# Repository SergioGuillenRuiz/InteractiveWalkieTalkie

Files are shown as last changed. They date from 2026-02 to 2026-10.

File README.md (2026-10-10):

# Proyecto Gogoaty — walkie-talkie LoRa con pantalla

Un par de equipos de bolsillo (ESP8266 + módulo LoRa SX1276 + pantalla OLED, **dos botones y un potenciómetro**)
que se mandan mensajes cifrados por radio, sin móvil ni internet: texto en Morse, mensajes rápidos con icono,
letras con una rueda, frases por piezas y dibujos de 24×24 píxeles. Un hipopótamo anima la pantalla, avisa
cuando llega algo y se duerme solo. Incluye varios juegos (Tetris cooperativo, Poker, Tres en raya…) y un radar
para localizar al otro equipo. Versión del firmware: **V2.0**.

> **Estado.** Todo lo descrito aquí está verificado en el **simulador** (`sim/`, más de 40 tests con la radio y el
> chip modelados). **Falta probarlo en la placa**: ver [`path.md`](path.md) (hoja de ruta, riesgos y decisiones
> pendientes).

---

## Componentes

```
                           BILL OF MATERIALS

 REF    | COMPONENTES      | ESPECIFICACIONES           | QTY
--------|------------------|----------------------------|------------
 ES     | Microcontrolador | ESP8266 (Generic)          | 1
 LO     | LoRa Module      | SX1276 (868 MHz)           | 1
 OLD    | OLED Display     | Monochromatic I2C (4-pin)  | 1
 PR     | Push Buttons     | Generic Tactile            | 2
 PTR    | Potentiometer    | Generic Analog             | 1
 PWR    | Power Source     | 3.2V LiPo Battery          | 1
```

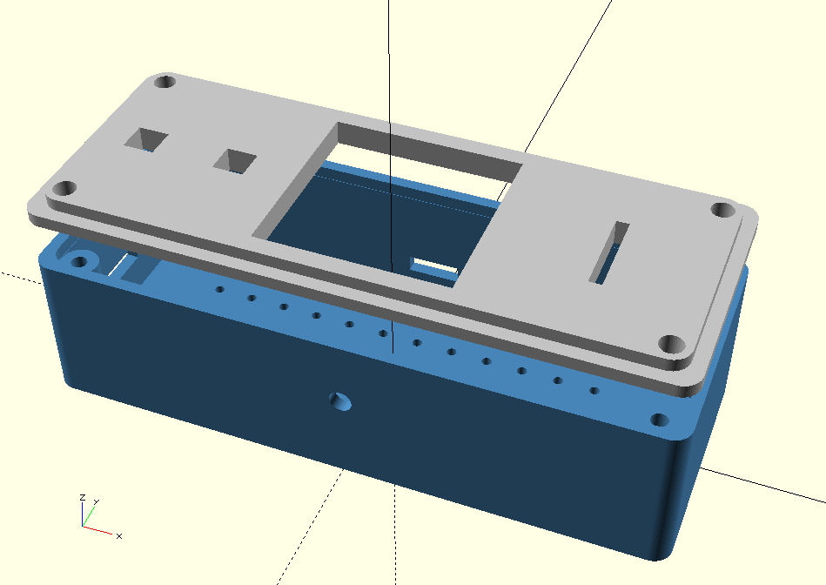
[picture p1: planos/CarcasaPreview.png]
Vista previa de la carcasa


* Nota: El proyecto utiliza placas genéricas para el microcontrolador y la pantalla,
  usar otra placa diferente no debería suponer un problema, en caso de error,
  consulta el manual y especificaciones de la placa, probablemente se deberá a una distinta
  distribución de pines.

### Conexiones

Los pines están en [`include/Config.h`](include/Config.h). Con una placa NodeMCU (`nodemcuv2`):

| Función | GPIO | Pin NodeMCU | Notas |
|---|---|---|---|
| LoRa NSS (CS) | 15 | D8 | |
| LoRa RST | 16 | D0 | |
| LoRa DIO0 | 5 | D1 | |
| LoRa SCK / MISO / MOSI | 14 / 12 / 13 | D5 / D6 / D7 | SPI por hardware (los fija el chip) |
| Botón **A** (Morse) | 4 | D2 | a masa al pulsar (con pull-up interno) |
| Botón **B** (Finish) | 0 | D3 | a masa al pulsar; **no lo mantengas pulsado al encender** (GPIO0 = modo de carga) |
| OLED SDA | 2 | D4 | I²C, dirección `0x3C` |
| OLED SCL | 3 | RX | el SCL va al pin RX: **el equipo no puede recibir datos por el puerto serie** (por eso la hora se pone con el menú) |
| Potenciómetro | A0 | A0 | el único ADC del ESP8266 |

**Antena:** conecta siempre la antena **antes** de encender el equipo; emitir sin ella puede dañar el módulo LoRa.

### Compilar y cargar el firmware

Con [PlatformIO](https://platformio.org/) (las librerías se descargan solas, ver [`platformio.ini`](platformio.ini)):

```bash
pio run                  # compilar
pio run -t upload        # cargar en la placa conectada por USB
pio device monitor       # registro serie a 115200 baudios
```

Carga **el mismo firmware en los dos equipos**: comparten clave de cifrado y parámetros de radio. Cada equipo
tiene un número propio (**"Equipo #N"**, de 1 a 254, derivado del chip y visible en el registro serie al arrancar).

---

## Manual de usuario

### Controles

El equipo se maneja con dos botones y el potenciómetro:

| Control | Para qué sirve |
|---|---|
| **Potenciómetro** | Mueve el cursor / elige una opción / cambia un valor |
| **Botón A** | Aceptar, entrar, "poner", avanzar |
| **Botón B** | Volver, salir, borrar |
| Pulsación **larga** | Acciones especiales (enviar, cancelar…): se indican en cada pantalla |

### Pantalla principal

Tres iconos en fila (gira el potenciómetro para mover el cursor y pulsa **A** para entrar) y el hipopótamo debajo:

* **Env** — enviar un mensaje. **Hist** — historial de mensajes. **Jueg** — juegos.
* **Barra superior:** a la izquierda, tu batería; en el centro, la **hora** (`--:--` si nadie la ha puesto);
  a la derecha, el **corazón** (vacío = nadie en alcance; lleno = al menos un compañero cerca) y, junto a él, la
  **batería del compañero** (la más baja de los que están en alcance; un `!` indica que alguno tiene la batería baja).
* **Insignia en "Hist"**: número de mensajes **sin leer** (`9+` si hay más de 9).
* Cuando llega un mensaje, el hipopótamo **persigue al corazón**.
* **Mantén B 1,5 s** en esta pantalla para **poner la hora** (ver más abajo).

### Enviar un mensaje

**Env → eliges el modo con el potenciómetro y pulsas A.** Hay cinco modos (B vuelve):

| Modo | Cómo se usa |
|---|---|
| **Morse** | **A corta** = punto, **A larga** (≥ 0,25 s) = raya. **B corta** cierra la letra. **B larga** (1,5 s) **envía**. **A muy larga** (2 s) cancela. Cinco puntos (`.....`) = espacio. La pantalla enseña la tabla Morse. Sin tocar nada 45 s, cancela. |
| **Instant** | Ocho mensajes con icono: *cansada, hambrienta, meh, kissy, happy, busy busy, Zi, Nour*. Gira el potenciómetro y pulsa **A** para enviar. |
| **Rueda** | Escribe texto libre: el potenciómetro elige la letra (espacio y A–Z), **A** la añade, **B corta** borra la última, **B larga** **envía**, **A larga** cancela. |
| **Frase** | Compón una frase por piezas **Sujeto + Verbo + Objeto**: el potenciómetro elige la opción de cada categoría, **A** la fija y pasa a la siguiente (en la última, envía), **B corta** retrocede, **B larga** envía ya. **A larga** gestiona tus **piezas propias** (se escriben con la Rueda y se guardan en el equipo). |
| **Dibujar** | Lienzo de 24×24: el potenciómetro mueve el cursor **arriba/abajo**; **mantén A** (0,3 s) y gira para moverlo a **izquierda/derecha**; **A corta** pinta un punto, **B corta** lo borra; **mantén B** (1,5 s) para **enviar**. Sin tocar nada 25 s, descarta el dibujo. |

El texto de un mensaje admite hasta **92 caracteres** (sin tildes ni eñes: la fuente de la pantalla no las tiene).

Al enviar sale una pantalla con el resultado:

* **Enviado — esperando confirmación…** → al llegar al otro equipo pasa a **¡Entregado!** (con un tic) y "visto por el otro".
* Si en unos 3 s no llega la confirmación: **(sin confirmar)**. No pasa nada: el equipo **reintenta solo** (hasta 3 veces,
  cada ~5 s) y, si el compañero estaba fuera de alcance, lo reenvía en cuanto vuelva a oírlo. Los mensajes pendientes
  **sobreviven a un reinicio**.
* **A** vuelve a empezar (otro mensaje), **B** vuelve al menú principal.

Si varios equipos reciben el mismo mensaje, todos lo confirman; basta la primera confirmación para marcarlo como entregado.

### Historial

**Hist** muestra los **10 últimos mensajes** (recibidos y enviados; al llegar el undécimo se descarta el más
antiguo). Se guardan en el equipo y **sobreviven a un reinicio**.

* Cada fila indica la antigüedad (`3m`, `--` si no se conoce), el texto y, si es tuyo, `Tu:`. Un **punto** marca los **no leídos**.
* El potenciómetro recorre la lista; **A** abre el mensaje completo ("De #N" o "Enviado" y cuánto hace); **B** sale.
* Dentro de un mensaje: **A** = borrar (te pide confirmar: **A** sí, **B** no), **B** = volver.
* Los **dibujos** salen como `[dibujo]` y al abrirlos se ven completos, también los que enviaste tú.
* Un mensaje pasa a *leído* al abrirlo o al salir de la lista si su fila llegó a verse.

### Avisos y suspensión

* A los **5 minutos sin tocar nada** el equipo se **suspende**: apaga la pantalla (y la CPU descansa), pero la **radio sigue escuchando**.
* Si llega un mensaje o un dibujo con la pantalla apagada, **se enciende 8 s** con una vista previa (*Mensaje nuevo — De #N*):
  **A** lo abre en el Historial, **B** la cierra; si no pulsas, se apaga sola.
* Para **despertar**, pulsa un botón **3 veces** (en menos de 45 s).

### Poner la hora

El equipo no tiene reloj propio: la hora se pone **una vez** y se **comparte por radio**.

1. En la pantalla principal, **mantén B** 1,5 s → **Poner la hora**.
2. Con el **potenciómetro** eliges las **horas**; **A** pasa a las **decenas de minuto**, otra vez **A** a las **unidades**, y **A** guarda. **B** vuelve atrás (en las horas, cancela).
3. El otro equipo **adopta la hora** en cuanto oye la baliza (la última hora puesta gana, aunque sea anterior). La hora se guarda y es la **hora local**: al cambiar de horario de verano/invierno hay que ponerla de nuevo.

La hora se usa para la antigüedad de los mensajes ("hace 3m").

### Juegos

**Jueg** → elige con el potenciómetro (A entra, B sale):

| Juego | Cómo se juega |
|---|---|
| **Tetris Coop** | Tablero **cooperativo** compartido. Modos: *Jugar con CPU*, *2 Jug: Crear* (anfitrión) y *2 Jug: Unirse* (invitado, con otro equipo por radio). **Potenciómetro** = columna de la pieza, **A** = girar, **B corta** = caída rápida, **mantén B** = salir. |
| **Poker** | Texas Hold'em contra la CPU (1000 fichas, ciegas 10/20). **B** cambia de acción (igualar/pasar, subir, retirarse) y **A** confirma. |
| **RefillGame** | "La Cervecería": llegan jarras; el **potenciómetro** regula el caudal del grifo y **A** para y entrega la jarra. Gana puntos cuanto más cerca de la marca; desbordar o quedarse corto cuesta una vida (3). |
| **Choose4Me** | Una bola mágica: piensa una pregunta, **A** para preguntar; **B** sale. |
| **HippoRadar** | Localiza al otro equipo: **ambos** abren el radar (A para empezar). Pasa de *BUSCANDO* a *GIRA DESPACIO* (frío / tibio / caliente) y, al bloquearse, a *VE HACIA AQUÍ* con una flecha y la distancia estimada. **A** reinicia la búsqueda, **B** sale. **Mientras dura el radar el equipo no recibe mensajes** (usa otra configuración de radio de más alcance); al salir se anuncia y reintenta lo pendiente. |
| **3 en raya** | Para dos equipos. Emparejamiento automático ("Buscando rival…"): el equipo con el número **menor** juega con la **X** y mueve primero. **Potenciómetro** elige la casilla, **A** coloca la ficha; **mantén B** para salir. |

**Los mensajes siguen llegando mientras juegas** (Tetris, Tres en raya, HippoRadar…): se guardan en el Historial y se confirman,
y los verás como no leídos al salir al menú. (En el radar de HippoRadar, no: ver arriba.)

### La radio

* Banda de **868 MHz**, modulación LoRa **SF7**, 125 kHz; los mensajes van **cifrados (AES-128)**.
* **Alcance:** depende de la antena y del entorno (todavía no medido en la placa). El radar usa un modo
  de más alcance (SF10, +20 dBm).
* **Presencia:** cada equipo emite una **baliza** cada ~30 s; si un compañero lleva más de 90 s sin oírse se considera fuera de alcance
  (el corazón se vacía).
* **Varios equipos:** el sistema recuerda hasta **4 compañeros** a la vez; los mensajes se difunden a todos.
* **Uso responsable:** en la banda de 868 MHz de la Unión Europea hay límites de potencia y de tiempo de emisión; ver el apartado
  *Límite legal* de [`path.md`](path.md).

### Solución de problemas

| Síntoma | Qué mirar |
|---|---|
| La pantalla no enciende / está en negro | ¿Está **suspendido**? Pulsa un botón 3 veces. Comprueba SDA/SCL y la dirección `0x3C`. |
| No se oyen los equipos | Mismo firmware en los dos, **antena conectada**, a menos distancia; que ninguno esté en el **radar** de HippoRadar. El registro serie muestra `[LoRa] ...` y `[Presencia]`. |
| Dos equipos que no se ven aunque están cerca | Pueden tener el **mismo número** (el identificador es de 1 byte derivado del chip: raro, ~0,4 %); en ese caso un equipo ignora los mensajes del otro. Compara "Equipo #N" en el registro serie al arrancar. |
| `--:--` en lugar de la hora | Nadie ha puesto la hora aún: mantén **B** 1,5 s en la pantalla principal. |
| El nivel de batería siempre marca 100 % | Es lo esperado hoy: el único ADC del ESP8266 lo usa el potenciómetro y medir la batería requiere hardware dedicado (ver `path.md`). |
| El equipo no arranca con la placa conectada | No mantengas pulsado **B** (GPIO0) al encender. |

---

## Simulador y pruebas

El directorio [`sim/`](sim/) contiene un **simulador nativo de PC** que compila y
ejecuta el firmware real (`src/`) sin necesidad de hardware: renderiza la pantalla
OLED 128×128, simula botones, potenciómetro y la radio (el **chip SX1276 a nivel de registros**, con tiempos en el aire,
half-duplex y colisiones; cifrado AES real), y permite tanto un **modo interactivo por teclado** como **tests automatizados**
(también con **varios equipos a la vez**, con el mismo tiempo virtual y resultados deterministas).

```bat
cd sim
run_tests.bat            :: compila y ejecuta toda la batería de tests
run.bat                  :: modo interactivo (teclado)
```

Requiere *Visual Studio Build Tools* (C++). Más detalles en [`sim/README.md`](sim/README.md).

En **Linux (GNOME)** hay una versión equivalente y separada en [`sim/linux/`](sim/linux/):

```bash
cd sim/linux
./run_tests.sh           # compila y ejecuta toda la batería de tests (42 suites)
./net_test.sh            # pruebas con varios equipos a la vez sobre el "aire" compartido
./run.sh                 # modo interactivo (abre una ventana de GNOME Terminal)
```

Requiere `g++`/`gcc`. Más detalles en [`sim/linux/README.md`](sim/linux/README.md).

La hoja de ruta (qué está terminado, qué falta, riesgos y decisiones pendientes) está en [`path.md`](path.md).

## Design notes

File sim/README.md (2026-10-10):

# Simulador nativo del walkie-talkie

Simulador de PC que **compila y ejecuta el firmware real** de `../src` (la misma
`setup()`/`loop()`, la misma máquina de estados, el mismo Adafruit_GFX y el mismo
tiny-AES que la placa). Permite probar las funcionalidades y la navegación de los
menús **sin tocar el hardware**, de forma rápida, reproducible y automatizable.

No es una reimplementación: la lógica que se ejecuta es exactamente la del
microcontrolador. Solo se sustituye la capa de hardware (Arduino core, OLED, LoRa,
botones, potenciómetro, EEPROM) por una capa *mock* equivalente.

```
        TU FIRMWARE (../src/*.cpp)  ── sin cambios ──┐
                                                      │  compila con MSVC
   capa mock Arduino  (sim/arduino) ─────────────────┤  -> walkie_sim.exe
   Adafruit_GFX + tiny-AES reales (sim/vendor) ──────┤
   motor del simulador (sim/engine) ─────────────────┘
```

## Requisitos

- **Visual Studio Build Tools** (o Visual Studio) con *"Desktop development with C++"*
  (proporciona `cl.exe`). El script lo localiza automáticamente con `vswhere`.
- Windows. (No requiere PlatformIO, ni internet, ni token de Wokwi.)

> **¿Linux?** Hay una versión equivalente (GNOME, g++) en [`linux/`](linux/README.md)
> con sus propios scripts (`build.sh`, `run.sh`, `run_tests.sh`, `net.sh`,
> `net_test.sh`). Usa el mismo firmware, motor y scripts de prueba que esta.

## Uso rápido

```bat
cd sim

run_tests.bat          ::  compila y ejecuta TODA la batería de tests
run.bat                ::  compila y abre el modo INTERACTIVO (teclado)
run.bat scripts\nav.sim::  compila y ejecuta un script concreto
build.bat              ::  solo compilar -> out\walkie_sim.exe
```

### Modo interactivo (teclado)

```
[m] / [n]              pulsar (tap) Morse / Finish
[Shift+M] / [Shift+N]  pulsación larga Morse / Finish
[Flecha arriba/abajo]  girar el potenciómetro (+ / -)
[r]                    simular recepción LoRa ("happy")
[q]                    salir
```
Las teclas también se muestran bajo la pantalla mientras corre. La pantalla OLED
128×128 se dibuja con **medios bloques** (`▀ ▄ █`): cada carácter pinta 2 píxeles
verticales rellenos, así los píxeles salen **cuadrados y sólidos**, igual que el
OLED real. Ocupa siempre **128×64 caracteres** (alto fijo), por lo que el terminal
debe tener al menos 128 columnas y ~68 filas; **maximiza la ventana** y, si no
cabe entera, **reduce la fuente** (Ctrl + −) — eso además hace los píxeles más
pequeños y más parecidos al hardware.

El modo interactivo corre el firmware en tiempo real y lee el teclado **incluso
mientras un juego o menú está esperando una pulsación**, de modo que se puede
entrar y jugar a cualquier pantalla (Poker, Choose4Me, etc.) sin bloqueos.

### Reproducir teclas con guion (demos / pruebas)

`run.bat --keys guion.txt` reproduce una secuencia de teclas sin necesidad de
teclado. Cada línea es `<ms> <acción>`, donde `ms` son milisegundos (virtuales)
desde el arranque y la acción es una tecla (`m`, `n`, `M`, `N`, `r`, `q`) o
`pot <valor>`. Útil para reproducir un fallo o grabar una demo de un juego.
Conviene maximizar la ventana del terminal (necesita ~34 líneas de alto).

## Comunicación multi-dispositivo (varios equipos a la vez)

Para probar la comunicación **real** entre equipos, el simulador puede unir varios
procesos en un **"aire" compartido**: lo que **transmite** un dispositivo lo
**reciben** todos los demás (menos él mismo, half-duplex), igual que la difusión
RF real. Cada proceso es un dispositivo **independiente y real**: su propio
firmware, su propia EEPROM y su propia identidad de equipo (`Device_id`).

No es una maqueta: el cifrado AES, el sobre de chat, el auto-ACK de entrega y el
historial son los mismos que en la placa. Lo único simulado es el medio (un
directorio donde cada transmisión es un fichero de paquete que los demás leen).
Como en la radio real, un equipo solo oye lo que se emite mientras está
encendido (si arranca después, no recibe los mensajes anteriores) y cada paquete
caduca a los 10 s y se borra, así el directorio no crece en sesiones largas.

### Interactivo — varias ventanas que se hablan

```bat
cd sim
net.bat 3      ::  abre 3 dispositivos, cada uno en su ventana, comunicados por radio
net.bat        ::  por defecto, 2 dispositivos
```

Cada ventana es un equipo con su teclado (`m`/`n`, mayúsculas para pulsación larga,
flechas para el potenciómetro, `q` para salir). Envía un mensaje desde uno y
aparecerá en el historial de los demás; verás la confirmación **"Entregado"** en
el emisor cuando otro equipo lo recibe.

### Automatizado — para testear futuras funciones de comunicación

`net_test.sh` (Linux) / `net_test.ps1` (Windows) lanza varios dispositivos en paralelo (sin teclado),
conducen un intercambio y comprueban aserciones sobre lo que cada uno recibió. Son la **plantilla
para probar futuras funciones** que impliquen a más de un equipo:

```bat
cd sim
powershell -ExecutionPolicy Bypass -File net_test.ps1     ::  Windows
./linux/net_test.sh                                       #   Linux
```

Escenas: difusión de 1 equipo a 2 (con los ACK de ambos), mensajes en los dos sentidos, **emisión
simultánea** (las dos tramas se pisan y se recuperan por reintentos), hora puesta a mano que adopta
otro equipo, tres equipos viéndose por las balizas, un **dibujo** de un equipo a otro (con su confirmación) y
**cuatro equipos** donde los tres receptores confirman el mismo mensaje (los ACK salen con retardo aleatorio y no se pisan). Internamente cada equipo corre en modo `--keys`
(con guion de teclas) y comparte el aire con `--air <dir> --node <id>`; su salida serie y el resumen de
radio (`[radio]`: qué emitió y qué le llegó, y por qué se perdió lo que no oyó) se vuelcan a un fichero
y se comprueban.

#### Tiempo sincronizado entre procesos (`--nodes N`, Linux/macOS)

Con `--nodes N` los N procesos comparten **el mismo tiempo virtual** y avanzan juntos milisegundo a
milisegundo (barrera en memoria compartida: `<aire>/board.bin`). Lo que emite un equipo en el ms *t* lo
oyen los demás desde el ms *t+1* con su instante de inicio exacto, de modo que los tiempos en el aire, el
half-duplex y las **colisiones son los de la realidad** y el resultado es **determinista**: no depende de la
velocidad de la máquina ni del azar del arranque (las 7 escenas tardan ~2 s). Sin `--nodes` cada proceso
lleva su propio reloj, anclado al reloj de pared con `--pace`: sirve para ver la comunicación funcionando
(es lo que usa `net.sh` interactivo), pero los relojes quedan desfasados decenas de ms y dos tramas que en
la realidad se pisarían, o no, dependen del azar. En Windows el modo sincronizado no está disponible
(`net_test.ps1` usa el modelo `--radio ideal`, sin tiempo en el aire, con `--pace`).

## Tests automatizados

Los scripts viven en `scripts/*.sim`. Cada uno conduce el firmware y comprueba
aserciones; el ejecutable devuelve código de salida ≠ 0 si alguna falla.

| Script | Qué prueba |
|---|---|
| `nav.sim` | Navegación por los 3 menús y vuelta a IDLE |
| `send_instant.sim` | Enviar un mensaje predefinido + verificar el cifrado LoRa |
| `send_morse.sim` | Crear una letra en Morse y enviarla |
| `lora_rx.sim` | Recepción LoRa: descifrado y guardado en historial |
| `history.sim` | Recibir varios mensajes, verlos y borrar uno |
| `chat.sim` | Chat: id de emisor, auto-ACK, enviados en historial, entrega y fechas tras reinicio |
| `sleep_wake.sim` | Suspensión por inactividad y despertar con 3 pulsaciones |
| `games.sim` | Poker, Choose4Me y juego "Próximamente" (incluye regresiones) |
| `reliable.sim` | Entrega fiable: dedup de RX + reintentos + outbox persistente (sobrevive a reboot) |
| `presence.sim` | Presencia del compañero por baliza: online tras oírla, offline tras el timeout |
| `clock.sim` | Reloj compartido: hora fijada/sincronizada, antigüedad real y persistencia tras reboot |
| `battery.sim` | Aviso de batería baja con histéresis (medidor + "!" en la barra de estado) |
| `doodle.sim` | Lienzo 24×24: editor, envío con pantalla de resultado ("Enviado" → "Entregado!" / "(sin confirmar)"), reintentos, el dibujo enviado y el recibido en el Historial |
| `ttt_rx.sim` | Chat DENTRO de Tres en raya: mensaje guardado y confirmado sin interrumpir la partida, baliza, ACK ajeno y paquetes de otros juegos sin basura en el historial, balizas y reintentos durante la partida |
| `tetris_rx.sim` | Lo mismo dentro de Tetris Coop (cliente): lobby y partida, con la ocupación del canal (~26 %) |
| `tetris_host.sim`  | Tetris Coop como anfitrión: chat en el lobby y en la partida, entrada del invitado y ocupación del canal por debajo del 55 % (el estado sale cada 340 ms con paquetes de 118 ms) |
| `hippo_rx.sim` | HippoRadar (SF10) y el chat: pings por la cola de juego, el chat (SF7) no se oye durante el radar, sin balizas ni reintentos mientras dura, y al salir se anuncia y el chat vuelve |
| `doodle_store.sim` | Dibujos persistentes: el lienzo vive en su registro del Historial (sobrevive a reinicios, sigue a su registro al desplazarse o borrarse, sin duplicados, outbox persistente con el mismo lienzo) |
| `clock_set.sim` | Pantalla "Poner la hora": abrir (B mantenida), tres pasos con el pote, cancelar, guardar, persistencia, radio activa durante el ajuste |
| `clock_gen.sim` | Autoridad de la hora entre equipos (generación de ajuste: más reciente gana aunque sea hacia atrás, igual converge, vuelta del contador, baliza antigua) y edades del historial conservadas |
| `radio_model.sim`  | Autotest del modelo de radio: la librería LoRa real contra el chip simulado (tiempos en el aire del roadmap, bloqueo al transmitir, reglas de recepción) |
| `radio_rx.sim` | La radio escucha SIEMPRE (menú, juegos, esperas bloqueantes, tras emitir), vigilancia que re-arma un chip caído, sueño de la radio solo en suspensión prolongada y consumo |
| `radio_csma.sim` | Acceso al canal: escuchar antes de hablar, no destruir una trama sin leer al emitir, leer una trama sin abortar la siguiente, ACK con retardo aleatorio y reintentos con dispersión |
| `unread.sim` | Mensajes no leídos: insignia, puntos de "nuevo", persistencia, leídos al abrir/salir de la lista, 9+, enviados y ACK/duplicados no cuentan |
| `sleep_alert.sim`  | Aviso con la pantalla apagada: vista previa 8 s, A lee / B cierra, no cuenta para el despertar, duplicados/ACK/balizas no avisan |
| `peers.sim` | Varios equipos: tabla de compañeros (presencia por equipo, batería mínima, tabla llena, mismo msgId de emisores distintos, dedup de 16, reactivar reintentos) |
| `beacon_jitter.sim`| Balizas con jitter: primera a los 2-4 s y siguientes cada 27-33 s, no todas iguales |
| `peer_batt.sim` | Batería del compañero junto al corazón de presencia (nivel, "!" de batería baja, oculta fuera de alcance) |
| `ui_fixes.sim` | Cursor del menú principal (no desaparece al dormir/despertar ni tras las animaciones), hora de la barra de estado y etiquetas del menú de juegos |
| `ttt.sim` | Tres en raya por LoRa: emparejamiento, roles, jugada y detección de fin |

Ejecutar uno con salida detallada:

```bat
out\walkie_sim.exe --fresh scripts\history.sim
```

## Lenguaje de scripts

Un comando por línea. Las líneas que empiezan por `#`, y todo lo que siga a ` # `
(almohadilla **precedida y seguida de espacio**), son comentarios. Un `#` pegado a un
texto forma parte del argumento: `expect serial ACK a #50` busca `ACK a #50`.

Un error en el propio guion (comando o comprobación desconocidos, argumentos que
faltan o no válidos, un mensaje inyectado demasiado largo para que el firmware
lo cifre, una captura que no se puede guardar) cuenta como `[FAIL]` e indica la
línea, para que una errata no deje pasar un test sin comprobar nada.

**Entradas**
```
pot <0-1023>            fija el potenciómetro
pot% <0-100>            fija el potenciómetro en %
morse down|up           estado del botón Morse (manual)
finish down|up          estado del botón Finish (manual)
tap morse|finish [ms]   pulsación completa (por defecto 150 ms)
hold morse|finish <ms>  pulsación larga
in <ms> morse|finish down|up   programa un evento dentro de <ms> (timeline)
in <ms> pot <v>                 programa un cambio de potenciómetro
```

**Tiempo** (ejecutan el `loop()` real avanzando el reloj virtual)
```
wait <ms>    avanza ejecutando el firmware
run <ms>     alias de wait (estilo timeline)
blind <ms>   el reloj avanza pero el firmware NO corre (como si estuviera ocupado en otra cosa)
ff <ms>      avance rápido (para timeouts largos, p.ej. el sueño de 5 min)
```

**LoRa**
```
lora rx <texto>     inyecta un mensaje entrante (lo cifra con la clave del firmware)
lora rxraw <hex>    inyecta los bytes de un paquete tal cual viajan por el aire (hex)
lora rxbin <hex>    inyecta un paquete cuyo texto PLANO son esos bytes (hex): lo cifra el firmware (p.ej. un paquete de
                    Tetris: `lora rxbin 5453` + 38 bytes; deferido: `in <ms> lorabin <hex>`)
lora loopback on|off  reenvía lo transmitido como recibido
lora tx <texto>     el FIRMWARE emite ese mensaje por su capa de radio (escuchar antes de hablar, etc.)
lora sent           muestra el último paquete transmitido (y su descifrado)
in <ms> lora <texto>  /  in <ms> chatmsg <emisor> <msgId> <texto>  /  in <ms> chatack <destino> <msgId>
                    el mismo paquete, entregado dentro de <ms> (también durante esperas bloqueantes)
chatmsg <emisor> <msgId> <texto>   inyecta un MENSAJE de chat de un peer (con sobre)
chatack <destino> <msgId>          inyecta un ACK de un peer (confirmación de entrega)
presence <peerId> [epoch] [batt] [gen]   inyecta una BALIZA de presencia de un peer
                                   (gen = generación de ajuste de su hora; -1 = baliza antigua sin ese byte)
in <ms> presence <peerId> [epoch] [batt] [gen]   baliza diferida (durante esperas bloqueantes)
doodle <peerId> [msgId] [heart|frame]   inyecta un DIBUJO 24x24 de un peer: "heart" (por defecto, una masa
                                   en forma de corazón) o "frame" (marco + diagonal); msgId automático si falta
ttt hello <peerId>                 Tres en raya: inyecta el HELLO de emparejamiento de un peer
ttt state <peerId> <9digitos> <fin>   Tres en raya: inyecta un ESTADO del tablero (0/1/2 por casilla)
in <ms> doodle|ttt ...             variantes diferidas (durante el bucle bloqueante de un juego)
in <ms> expect|shot|print|radio ...   una COMPROBACIÓN, captura, nota o ajuste de radio diferido: se ejecuta en ese instante, también
                                   DENTRO de una espera bloqueante (un juego, una pantalla de resultado), donde
                                   un `expect` normal solo podría mirar al terminar el run
```

**Batería / hora / reinicio** (para las features de batería, presencia y reloj)
```
battery <0-100>        fija el nivel de batería simulado (canal ADC mockeado)
in <ms> battery <pct>  cambio de batería diferido (durante una espera bloqueante)
settime <epoch>        fija el reloj de pared (segundos epoch), lo persiste y sube la generación de ajuste
                       (equivale a "alguien puso la hora"; no reajusta las marcas del historial)
reboot-cold            reinicio EN FRÍO: re-ejecuta setup() Y pone millis()=0
```
`reboot-cold` conserva la EEPROM (es justo lo que se quiere probar: que algo
persista) y la batería mockeada, pero descarta los eventos diferidos pendientes
(`in <ms> ...` que aún no hayan vencido), igual que un reinicio real perdería
entradas en vuelo.

**Inspección y aserciones**
```
screen              dibuja el OLED en el terminal
text                imprime el texto dibujado en pantalla
serial              imprime el log serie del firmware
shot [nombre]       guarda una captura BMP en out\
expect text <sub>      la pantalla contiene <sub>
expect notext <sub>    la pantalla NO contiene <sub>
expect serial <sub>    el log serie contiene <sub>
expect sent <sub>      el último TX LoRa descifra y contiene <sub>
expect sentdoodle <msgId> <píxeles> [x y]   algún TX reciente es un dibujo con ese msgId y ese nº de píxeles
                       encendidos (y, si se dan, el píxel (x,y) encendido)
expect times <n> <sub>   el log serie contiene <sub> EXACTAMENTE <n> veces
expect beacon gen|batt|epoch|time <v>   la última BALIZA transmitida lleva ese valor (time = HH:MM)
expect panel on|off    el panel OLED está encendido/apagado (la suspensión lo apaga)
expect pixel <x> <y> on|off   estado de un píxel
waitfor serial <min> <max> <texto>   ejecuta el firmware hasta que <texto> aparezca en el log serie (solo
                       lo nuevo) y comprueba que lo hace entre <min> y <max> ms (ritmo de balizas, reintentos)
waitfor clear          olvida las esperas registradas;  expect spread <ms>: entre ellas, max-min >= <ms>
waitfor txend          ejecuta el firmware hasta que la radio termine de emitir (la emisión es asíncrona: tras
                       `waitfor serial ... [Chat] Baliza` la baliza aún está en el aire)
watch pixel <x> <y> on|off <ms>   ejecuta el firmware <ms> y comprueba el píxel tras CADA vuelta de loop()
                       (detecta parpadeos que un expect puntual no ve)
print <texto>          imprime una nota
reboot                 re-ejecuta setup() (recarga el historial de EEPROM)
reset-eeprom           borra la EEPROM
```

### Ejemplo

```
wait 300
pot 80              # cursor en "Enviar"
wait 200
tap morse           # entrar
wait 200
expect text Selecciona
```

## Opciones del ejecutable

```
walkie_sim.exe [script.sim] [opciones]
  --interactive     modo teclado
  --keys <fich>     modo interactivo reproduciendo teclas con guion
  --fresh           borra la EEPROM al arrancar
  --color           color en el render del terminal
  --eeprom <fich>   fichero de respaldo de EEPROM (por defecto out\eeprom.bin)
  --shots <dir>     carpeta de capturas (por defecto la del .exe)
  --scale <n>       escala de las capturas BMP (por defecto 4 -> 512×512)
  --air <dir>       conecta este dispositivo al "aire" compartido (radio multi-dispositivo)
  --node <etiqueta> identidad única en el aire (para no oír lo propio)
  --rssi <dBm>      potencia con que los demás oyen sus transmisiones (por defecto -50)
  --radio real|ideal  modelo de radio: real (por defecto) = chip SX1276 con tiempo en el aire (la
                    radio solo oye lo que llega mientras escucha, y transmitir bloquea); ideal =
                    siempre escucha y sin tiempo en el aire (comportamiento antiguo)
  --nodes <N>       modo sincronizado (Linux/macOS): los N procesos que comparten --air avanzan
                    juntos el mismo tiempo virtual (ver "Tiempo sincronizado entre procesos")
  --pace <x>        con --keys y sin --nodes: tope de velocidad del tiempo virtual (x ms virtuales
                    por ms real; 0 = sin tope). Con varios procesos en el aire compartido y sin
                    --nodes hace falta: sin tope cada uno corre su tiempo casi instantáneo y deja de
                    coincidir con los demás
```
Sin script y sin `--interactive`, lee comandos por la entrada estándar.
Una opción desconocida o sin su valor, o un guion de teclas que no existe, termina
con código 2. Las carpetas de `--shots` y de `--eeprom` se crean si no existen.
Para dar un id de equipo distinto a cada dispositivo, exporta `SIM_CHIPID` antes de
lanzarlo (`Device_id()` lo deriva de ahí en el simulador, y también siembra su aleatorio:
cada equipo sortea distinto, como la placa con su RNG por hardware). `SIM_SEED=<n>` cambia la secuencia aleatoria
SIN cambiar la identidad: sirve para ejecutar un test con muchas secuencias (retardos de ACK, dispersión de
reintentos y balizas) y descubrir los que solo pasan con una combinación afortunada de tiempos
(`for s in $(seq 1 50); do SIM_SEED=$s ./out/linux/walkie_sim --fresh scripts/x.sim; done`).

## Modelo de radio (chip SX1276 + librería real)

El firmware llama a la librería **LoRa real** (`vendor/lora`, arduino-LoRa 0.8.0, sin modificar) y por
debajo hay un **modelo del chip SX1276 a nivel de registros** (`engine/sx127x.cpp`) enganchado al SPI y a
los pines NSS/RST/DIO0. Reproduce lo que hace el silicio:

- **modos** SLEEP / STDBY / TX / RX continuo / RX único (con su caducidad de 100 símbolos ≈ 102 ms a SF7),
  banderas IRQ que se borran escribiendo 1, FIFO de 256 bytes;
- **transmitir tarda el tiempo en el aire real** (fórmula del datasheet con SF, BW, CR, preámbulo, CRC). Los
  paquetes del firmware van en **binario** (IV de 16 B + bloques AES de 16 B): un mensaje corto o una baliza son
  32 B = 72 ms a SF7, el estado de Tetris 64 B = 118 ms, un dibujo 96 B = 164 ms, un mensaje largo 112 B = 190 ms
  y un ping del radar a SF10 32 B = 453 ms. `endPacket()` de la librería bloquea ese tiempo; el firmware emite en
  modo asíncrono (`endPacket(true)`) y sigue con su bucle. Mientras transmite **no escucha** (half-duplex);
- **recibir**: una trama solo se oye si el chip está en un modo de recepción cuando se detecta su preámbulo y
  sigue en él hasta que termina; en STDBY/SLEEP/TX se pierde, con otro SF/BW/frecuencia/sincronismo no se
  demodula, dos tramas solapadas se pierden, con CRC activo una trama corrupta levanta `PayloadCrcError` (sin
  CRC llega alterada) y una trama sin leer la pisa la siguiente;
- **estadísticas**: tiempo emitiendo, destino de cada trama recibida y consumo estimado del chip por modo.

Los comandos `lora rx`, `chatmsg`, `presence`... inyectan una trama que **empieza en ese instante** con los
parámetros del proyecto (`radio peer ...` los cambia). `--radio ideal`
da el comportamiento antiguo: la trama se entrega al instante y siempre, y transmitir no cuesta tiempo.

**Escribir tests con este modelo.** Una trama inyectada ocupa el canal lo que dura en el aire (un mensaje
corto ~70 ms; uno largo ~190 ms; un dibujo ~160 ms) y el equipo contesta con su ACK, que sale entre 10 y 300 ms
después de recibir y dura otros ~70 ms: dos inyecciones a la vez, o una que llegue mientras el equipo
emite su ACK, se pisan y no se oye ninguna, igual que con la radio real. Por eso los guiones separan los
mensajes (≥ 800 ms entre uno y el siguiente, con `in <ms> chatmsg|lora|presence ...` o con `run`) y, antes de inyectar
tras un `ff` o justo tras el arranque, esperan a la baliza propia y a que acabe de emitirse
(`waitfor serial 0 40000 [Chat] Baliza` + `waitfor txend`; justo después el canal queda libre unos 27 s).
Los equipos inyectados son **educados**: no empiezan a emitir mientras el firmware está emitiendo, sino que
esperan a que acabe (`radio peer polite off` lo desactiva). Queda la ventana física que ningún equipo evita:
si el firmware empieza a emitir en los ~3 ms (3 símbolos de preámbulo) que tarda en detectar una trama ajena,
las dos se pisan; es muy improbable y por eso conviene probar los tests con varias semillas (`SIM_SEED`).

```
radio ideal on|off     cambia de modelo durante un guion
radio peer sf|bw|crc|preamble|sync|freq <v>|polite on|off|reset   parámetros con que emiten los "otros equipos" inyectados
radio deepsleep <ms>   ahorro opcional (Lora_setDeepSleepMs): la radio se duerme tras <ms> sin oír nada en suspensión (0 = nunca, el valor por defecto)
radio mark             punto de partida de los contadores (expect rx / expect tx)
radio report           resumen: tramas emitidas y su tiempo en el aire, destino de las recibidas, consumo
radio log              destino de cada trama recibida desde la marca
radio selftest         autotest del chip con la librería real (ver scripts/radio_model.sim)
expect rx heard|lost|crc|standby|sleep|tx|timeout|aborted|collision|mismatch|overrun [=|>=|<=] <n>
expect tx <min> <max>             tramas emitidas desde la marca
expect txstart <min> <max>        la 1a emisión desde la marca empieza entre min y max ms después de ella
expect airtime <max%> <ventanaMs> ocupación del canal por este equipo en la última ventana (se puede diferir: in <ms> expect airtime ...)
expect listening on|off           la radio está en recepción ahora mismo
expect radiomode sleep|stdby|tx|rxcont|rxsingle
```

## Fidelidad respecto al hardware real

| Aspecto | Simulador |
|---|---|
| Lógica del firmware | **idéntica** (compila `../src` sin cambios) |
| Render OLED | **idéntico** (Adafruit_GFX + fuente reales, 128×128, 1 bpp) |
| Cifrado de mensajes | **idéntico** (tiny-AES real, AES-128-CBC + PKCS7; paquete binario IV + bloques) |
| Historial / EEPROM | respaldado en fichero; persiste entre ejecuciones |
| Botones (antirrebote) | reloj virtual; el antirrebote se ejerce de verdad |
| Potenciómetro | valor 0–1023 controlable |
| LoRa (SX1276) | librería real + chip SX1276 simulado (ver "Modelo de radio"); **aire compartido real entre varios procesos** (`--air`) |
| Tiempos | reloj virtual determinista (no en tiempo real, salvo modo interactivo) |

Diferencias: no se simula el RF físico (ruido, alcance), ni el ruido del ADC, ni
la latencia exacta del bus I²C. Para eso haría falta el hardware real.

## Estructura

```
sim/
  arduino/    capa mock del core de Arduino (Arduino.h, Wire, SPI, EEPROM, LoRa,
              Adafruit_SH110X host sobre GFX, String, Print, pgmspace)
  vendor/     librerías reales vendorizadas (Adafruit_GFX, tiny-AES, arduino-LoRa)
  engine/     motor: reloj virtual, eventos de entrada, framebuffer, modelo del chip SX1276, driver/main
  scripts/    scripts de prueba (.sim): la batería de tests
  demos/      guiones de demostración que recorren cada pantalla y la capturan
  out/        artefactos de compilación (ignorado por git)
  build.bat / run.bat / run_tests.bat
  linux/      versión Linux (GNOME): build.sh, run.sh, run_tests.sh, net.sh,
              net_test.sh + capa de plataforma (termios). Salida en out/linux/
```

## Cómo añadir un test

1. Crea `scripts/mi_test.sim` con comandos + `expect ...`.
2. `run.bat scripts\mi_test.sim` para depurarlo (usa `screen`/`shot`/`text`).
3. Quedará incluido automáticamente en `run_tests.bat`.

Consejos para que no sea frágil (la radio es realista: ver "Modelo de radio"):

- **Separa los mensajes inyectados ≥ 800 ms** y no inyectes justo tras el arranque ni tras un `ff`: espera antes a la baliza
  propia (`waitfor serial 0 40000 [Chat] Baliza` + `waitfor txend`).
- Los **juegos y las pantallas de resultado son bloqueantes**: programa todo con `in <ms> ...` dentro de un único `run`
  (incluidas las comprobaciones: `in <ms> expect ...`). Con `run <ms> <margen>` y un margen pequeño se corta la espera enseguida.
- Si un paquete que llega **justo cuando el equipo empieza a emitir** (una ventana de unos ms) rompería el test, **repítelo** como
  haría un emisor real que no recibe el ACK (mismo `msgId`: no se duplica).
- Para las ocupaciones del canal usa `expect airtime <max%> <ventanaMs>`.
- **Pruébalo con varias semillas** (`SIM_SEED=1..50`) antes de darlo por bueno.
- `demos/` contiene guiones de demostración (capturas de cada pantalla); no forman parte de la batería.

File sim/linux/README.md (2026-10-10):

# Simulador — versión Linux (GNOME)

Versión Linux del simulador nativo. Es **el mismo simulador** que el de Windows
(`../README.md`): compila el firmware real de `../../src` con la misma capa mock
(`../arduino`), las mismas librerías (`../vendor`), el mismo motor (`../engine`)
y los mismos scripts de prueba (`../scripts`). Solo cambia la capa de plataforma
y los lanzadores, que viven separados en esta carpeta:

| Windows (`sim/`) | Linux (`sim/linux/`) | Qué hace |
|---|---|---|
| `build.bat` (MSVC `cl`) | `build.sh` (g++/gcc) | Compila → `out/walkie_sim.exe` / `out/linux/walkie_sim` |
| `run.bat` | `run.sh` | Modo interactivo o un script |
| `run_tests.bat` | `run_tests.sh` | Toda la batería de tests |
| `net.bat` + `net.ps1` | `net.sh` | N dispositivos interactivos comunicados por radio |
| `net_test.ps1` | `net_test.sh` | Prueba automatizada multi-dispositivo (7 escenas). En Linux los procesos comparten el mismo tiempo virtual (`--nodes N`: colisiones reales y resultado determinista, ~2 s); `net_test.ps1` usa el modelo de radio ideal |
| `engine/console_win.cpp` | `console_linux.cpp` | Ajuste de la consola para píxeles cuadrados |
| `<conio.h>`, `<process.h>`  | `platform_linux.h` | Teclado sin eco (termios), pid, ruta del ejecutable |

Las compilaciones están separadas: Windows deja sus artefactos en `sim/out/` y
Linux en `sim/out/linux/` (ejecutable, objetos, EEPROM y capturas).

## Requisitos

- `g++` y `gcc` (C++17). En Debian/Ubuntu: `sudo apt install build-essential`;
  en Fedora: `sudo dnf install gcc-c++`; en Arch: `sudo pacman -S base-devel`.
- Para las ventanas: **GNOME Terminal** (`gnome-terminal`). Sin él, el modo
  interactivo se ejecuta en el terminal actual.
- Opcional: `xrandr` (calcula el zoom según el monitor) e ImageMagick (convierte
  las capturas BMP a PNG en `net_test.sh`).

## Uso rápido

```bash
cd sim/linux

./run_tests.sh            # compila y ejecuta TODA la batería de tests
./run.sh                  # compila y abre el modo INTERACTIVO en una ventana nueva
./run.sh --here           # modo interactivo en el terminal actual
./run.sh ../scripts/nav.sim   # ejecuta un script concreto
./build.sh                # solo compilar -> ../out/linux/walkie_sim
./net.sh 3                # 3 dispositivos, cada uno en su ventana
./net_test.sh             # prueba automatizada multi-dispositivo
```

`build.sh` es incremental (solo recompila lo que cambió) y compila en paralelo.
Admite las variables `CXX`, `CC` (p.ej. `CXX=clang++ CC=clang ./build.sh`) y `JOBS`.

### Modo interactivo

Mismas teclas que en Windows: `m` / `n` pulsar, `M` / `N` pulsación larga,
flechas arriba/abajo para el potenciómetro, `r` simula recepción LoRa, `q` salir.

El render cuadrado necesita 128 columnas y ~68 filas. `run.sh` y `net.sh` abren
GNOME Terminal con `--geometry=132x72` y un `--zoom` calculado para que quepa en
el monitor (lo mismo que `run.bat` consigue fijando la fuente de `conhost`). Si
no te encaja, fuerza otro zoom:

```bash
SIM_ZOOM=0.6 ./run.sh
```

Si la ventana se queda pequeña, el simulador pasa a la vista compacta (braille);
agranda la ventana o reduce el zoom (`Ctrl + -`) para volver a los píxeles
cuadrados. Al salir (también con `Ctrl+C`) se restaura el modo del terminal.

### Ejecutable directo

Las opciones son las mismas que las de `walkie_sim.exe` (ver `../README.md`):

```bash
../out/linux/walkie_sim --fresh ../scripts/history.sim
SIM_CHIPID=200 ../out/linux/walkie_sim --interactive --color --air /tmp/aire --node 2
SIM_SEED=7 ../out/linux/walkie_sim --fresh ../scripts/peers.sim   # otra secuencia aleatoria (retardos de ACK, jitter...)
```

Para descubrir tests que solo pasan con una combinación afortunada de tiempos, ejecútalos con muchas semillas:
`for s in $(seq 1 50); do SIM_SEED=$s ../out/linux/walkie_sim --fresh ../scripts/x.sim; done`.

## Notas de implementación

- `../engine/sim_main.cpp` es compartido; solo tiene unos pocos `#ifdef _WIN32`
  (cabeceras `conio.h`/`process.h`, `timeBeginPeriod`, `chcp` y el separador de
  ruta de la EEPROM). En Windows se compila exactamente igual que antes.
- `platform_linux.h` traduce las flechas VT (`ESC [ A` / `ESC [ B`) al formato de
  `conio` (`0xE0` + 72/80) y deja pasar intacta la respuesta DSR con la que el
  simulador mide el terminal.

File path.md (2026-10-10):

# Hoja de ruta del proyecto

Estado de las funcionalidades a fecha **2026-10-10** (commit `3f167da`).

> Todo lo "terminado" está verificado **solo en el simulador**: desde junio no hay
> pruebas en la placa real. El simulador no modela dos cosas que en la placa pueden
> fallar: cómo escucha la radio y cuánto tarda cada paquete en el aire (ver Riesgos).

Leyenda: ✅ terminado · 🟡 a medias · ⚪ sin implementar · 🔴 riesgo sin verificar en la placa

---

## ✅ Terminado (funciona y tiene tests en el simulador)

| Área | Funcionalidad |
|---|---|
| Menú | Menú principal (Enviar / Historial / Juegos) con el hipopótamo animado y dormido por inactividad; el cursor se repinta en cada vuelta (no desaparece tras dormir/despertar ni tras las animaciones) y las etiquetas del menú de juegos no se cortan |
| Enviar | **Morse**, **Instant** (8 iconos), **Rueda** de letras (hasta 60 caracteres), **Frase** (3 categorías + piezas propias guardadas en EEPROM), **Dibujar** (lienzo 24×24: se confirma con ACK como un mensaje, se reintenta hasta que llega y muestra "Enviado" → "Entregado!" / "(sin confirmar)") |
| Mensajería | Identificador por equipo, cifrado AES-128 con IV aleatorio, confirmación "Entregado", 3 reintentos, cola de pendientes persistente y descarte de duplicados |
| Historial | 10 mensajes guardados en EEPROM (los **dibujos**, enviados y recibidos, también: el lienzo vive en su registro, así que sobrevive a reinicios y sigue a su registro al desplazarse o borrarse), enviados marcados con "Tu:", vista completa y borrado con confirmación. Los recibidos entran como **no leídos** (bit persistente): insignia con el recuento sobre el icono "Hist" (9+), punto de "nuevo" en la fila y se marcan como leídos al abrirlos o al salir de la lista si su fila llegó a verse |
| Aviso | Mensaje o dibujo nuevo: el hipopótamo persigue el corazón en el menú principal; con la pantalla apagada (suspensión) se enciende 8 s con vista previa (**A** = leer, abre el Historial; **B** = cerrar; sin pulsar se apaga sola) y esas pulsaciones no cuentan para el despertar de 3 pulsaciones |
| Hora | Se pone a mano (mantener **B** 1,5 s en el menú principal → "Poner la hora": horas / decenas / unidades de minuto con el pote), se muestra en el menú principal y en el Historial, se difunde y es **autoritativa** entre equipos (generación de ajuste en la baliza: la última hora puesta gana aunque se corrija hacia atrás), persiste en EEPROM y las antigüedades del historial no cambian al saltar el reloj. Es la hora local (sin zona horaria: al cambiar la hora de verano/invierno hay que volver a ponerla). No se puede por puerto serie: el SCL del OLED va al pin RX |
| Presencia | Baliza cada 30 s ±3 s (aleatoria, para que dos equipos encendidos a la vez no se tapen) y corazón en pantalla cuando hay algún compañero en alcance. Recuerda hasta 4 compañeros **por separado** (id, último oído, batería); a la izquierda del corazón se muestra el nivel de batería **más bajo** de los que están en alcance (y "!" si alguno avisa de batería baja), no el del último que emitió |
| Suspensión | A los 5 min: apaga la pantalla, WiFi apagado; se despierta con 3 pulsaciones |
| Juegos | Tetris Coop (contra CPU y 2 jugadores), Poker contra CPU, RefillGame, Choose4Me, HippoRadar y Tres en raya por LoRa. No queda ningún "Próximamente" accesible. **El chat sigue funcionando durante las partidas** (Tres en raya, Tetris 2J, HippoRadar): `backgroundTick()` es el único que lee la radio, atiende el chat (mensajes al historial con su ACK, presencia, balizas, reintentos) y deja a cada juego solo sus paquetes. Excepción: en el radar de HippoRadar la radio va en SF10 y no oye ni emite el chat (ver "En espera de tu decisión") |
| Radio | Los paquetes viajan en **binario** (IV + bloques AES: un mensaje corto o una baliza = 72 ms en el aire a SF7, la mitad que antes en hexadecimal) y los juegos emiten a un ritmo que cabe en el canal: Tetris 2J ~35 % el anfitrión y ~26 % el invitado (estado cada 340 ms, entrada cada 280 ms), radar ~34 % (un ping de 453 ms a SF10 cada 1,2-1,5 s); el chat normal ocupa ~0,3 %. La emisión es **asíncrona** (el equipo sigue atendiendo botones y animaciones mientras la trama está en el aire). La radio **escucha siempre** en recepción continua (menús, juegos, esperas bloqueantes y tras cada emisión), con vigilancia que la re-arma si el chip cae. La FIFO se lee por SPI sin salir de recepción (leer una trama no corta la siguiente) y una trama ya recibida no se pierde al emitir (cola de recepción). **Escuchar antes de hablar**: si entra una trama se espera a que acabe y a una pausa aleatoria. Los **ACK** salen tras un retardo aleatorio de 10-300 ms (varios equipos no se pisan) y los **reintentos** se reparten ±1,5 s. Las balizas esperan si el canal está ocupado. CRC activado en el paquete |
| Manual | El `README.md` incluye el manual de usuario (conexiones, compilación, controles, enviar, historial, avisos, hora, juegos, radio y solución de problemas) |
| Simulador | Windows (`sim/`) + Linux (`sim/linux/`), 42 tests, multi-dispositivo y demos. **Modelo de radio realista** (por defecto): ejecuta la librería LoRa real sobre un chip SX1276 simulado a nivel de registros (modos, IRQ, FIFO, tiempo en el aire real, transmitir bloquea, solo se oye lo que llega mientras se escucha, colisiones, CRC); autotest en `scripts/radio_model.sim`; los guiones se ejecutan también con varias secuencias aleatorias (`SIM_SEED`). **Varios equipos con el mismo tiempo** (`--nodes N`, Linux): los procesos avanzan juntos ms a ms, así las colisiones entre equipos son las reales y la prueba (`net_test.sh`, 7 escenas) es determinista y tarda ~2 s |

---

## 🟡 A medias

- [ ] **Batería.** En la placa, la lectura siempre devuelve 100 % (`src/Battery.cpp:13`), porque el único ADC del ESP8266 lo usa el potenciómetro. Hace falta hardware (y, por tanto, también el nivel que envía la baliza es siempre 100 %).

---

## ⚪ Sin implementar

- [ ] Medición real de la batería (necesita hardware).
- [ ] Emparejamiento y seguridad:
  - La clave AES está fija en el código y es la misma para todos los equipos.
  - No hay autenticación de mensajes (cualquiera con el firmware podría suplantar a otro equipo).
  - No hay protección contra reenvíos de paquetes antiguos.
- [ ] Zumbador o vibración (opcional; no está en la lista de componentes).
- [ ] **Identificador de equipo de 1 byte.** El número de equipo (1..254) sale del chip (`ESP.getChipId() % 254 + 1`): dos equipos pueden coincidir (≈ 0,4 % con 2 equipos, ≈ 2,3 % con 4) y entonces uno ignora los mensajes del otro (los toma por eco propio). Ampliarlo a 2 bytes cambia el formato de los paquetes.

---

## 🔴 Riesgos sin verificar en la placa

- [ ] **Radio: comportamiento verificado solo en el simulador.** El simulador ejecuta la librería real sobre un modelo del chip, pero el modelo se escribió a partir del datasheet: en la placa hay que confirmar que (a) se oyen los mensajes en el menú principal y en las esperas, (b) `Lora_busy()` (registro `RegModemStat`) detecta de verdad una trama entrante para escuchar antes de hablar, (c) leer la FIFO por SPI sin salir de recepción no corrompe la trama siguiente, y (d) el consumo en suspensión (light sleep del ESP8266, radio siempre encendida ≈ 11 mA) es el esperado.

---

## ⏸ En espera de tu decisión

Nada de esto se ha cambiado hasta que lo decidas; en cada caso, lo que hay ahora es lo más sencillo y no te ata a ninguna opción:

- [ ] **Límite legal de ocupación y potencia (UE, 868 MHz).** Según la normativa europea de dispositivos de corto alcance (EN 300 220; verifica la vigente), la sub-banda 868,0-868,6 MHz tiene un límite de ocupación del **1 %** (36 s de emisión por hora) y de **14 dBm de potencia radiada** (25 mW). El equipo emite en 868,0 MHz con 125 kHz de ancho (el borde inferior de esa sub-banda: parte de la señal cae por debajo), a **+17 dBm** (+20 dBm en el radar) y los juegos por radio ocupan el 25-35 % del canal: Tetris 2J y el radar **superan con mucho el 1 %** mientras se juega (el chat normal, ~0,3 %, cabe). Nada de esto se ha cambiado. Opciones: (a) dejarlo (uso privado o de prueba, bajo tu responsabilidad); (b) bajar la potencia a 14 dBm y mover la frecuencia a 868,1-868,5 MHz (un cambio de una línea en `include/MyLora.h`), manteniendo los juegos; (c) limitar la ocupación al 1 % con un contador en el firmware (los juegos por radio dejarían de ser viables); (d) usar la sub-banda de 869,4-869,65 MHz (10 % de ocupación, 500 mW) o escucha-antes-de-hablar con salto de frecuencia, que permiten más ocupación. ¿Qué prefieres?
- [ ] **HippoRadar y el chat.** El radar usa largo alcance (SF10, +20 dBm) y la radio solo oye lo que llega con ese mismo SF: durante el radar el equipo **no recibe mensajes del chat** (van en SF7) ni los emite, y mientras tanto no saca balizas ni reintentos (al salir se anuncia y reintenta lo pendiente; los emisores reintentan solos). Alternativas: (a) dejarlo así (es lo que hay ahora; solo dura mientras se usa el radar); (b) alternar a SF7 unos instantes cada pocos segundos para seguir oyendo el chat (a costa de perder pings); (c) hacer el radar en SF7 (menos alcance, el chat sigue funcionando). ¿Cuál prefieres?
- [ ] **Ahorro de energía de la radio en suspensión.** Hoy la radio **no se duerme nunca**: el equipo está siempre alcanzable y puede avisar con la pantalla apagada, a cambio de ~11 mA continuos. La alternativa está implementada y probada pero desactivada (`LORA_DEEP_SLEEP` en `include/Config.h`, o `Lora_setDeepSleepMs()` en marcha): tras N minutos sin oír nada en suspensión la radio se duerme del todo, el equipo dura más y deja de oír (y de avisar) hasta que lo despiertes con 3 pulsaciones. ¿Siempre alcanzable, dormir tras N minutos (¿cuántos?) o un ajuste en el menú?

---

## Orden propuesto

1. [ ] **Probar en la placa** la recepción en el menú principal, la suspensión y el consumo, y los dos modos de la tabla. El simulador ya modela la radio (`--radio real`) y reproduce estos riesgos sin placa; falta confirmarlos en la placa.
2. [ ] **Batería real** (hardware + calibración) y mostrar la del compañero.
3. [ ] **Seguridad:** emparejamiento y clave por pareja.
4. [ ] **Pulido:** un aviso de "mensaje nuevo" dentro de los juegos (hoy el mensaje se guarda y se confirma pero solo se ve al salir al menú) y revisar el manual con el equipo real en la mano.

---

## Limitaciones conocidas del simulador (no son tareas pendientes)

- Cada vuelta de `loop()` cuesta mucho menos que en la placa (no se cuenta el envío de cada imagen a la pantalla por I²C): las animaciones que avanzan por vuelta, como las "Zzz", van más rápido.
- `expect text` comprueba el texto dibujado desde el último borrado completo de la pantalla, aunque parte ya no se vea. Ningún test actual pasa por ese motivo.
- El modelo de radio realista enfrenta UN equipo a tramas inyectadas por el guion; con varios procesos (`--air`) hay colisiones reales entre equipos solo si se usa `--nodes N` (Linux/macOS, ver `sim/README.md`): sin él cada proceso lleva su propio reloj y el resultado depende del azar del arranque. En Windows `net_test.ps1` usa `--radio ideal` (sin tiempo en el aire). No se simula el RF físico (ruido, alcance, captura de la trama más fuerte) ni el tiempo real de los accesos SPI/I²C.
- `net_test.ps1` y `build.bat` (Windows) no se han probado desde que se añadió el modelo de radio realista: el entorno de desarrollo es Linux.

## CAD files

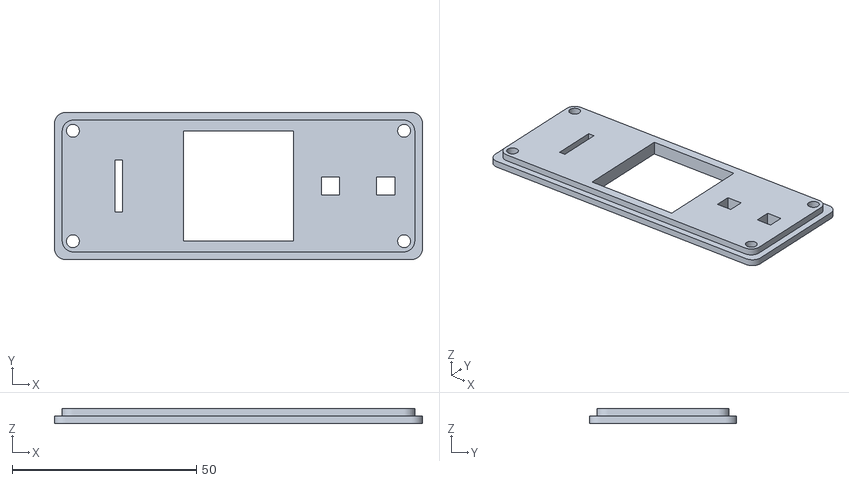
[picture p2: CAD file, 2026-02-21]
planos/ImprimibleTapaCarcasa.stl
100.0 x 40.0 x 4.00

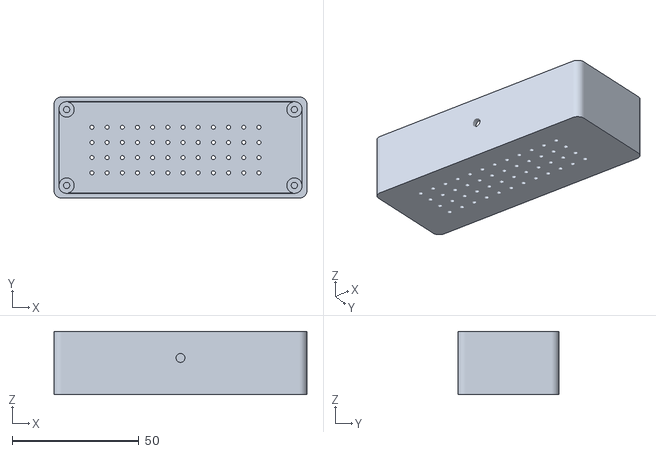
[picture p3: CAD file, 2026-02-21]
planos/ImprimibleBaseCarcasa.stl
100.0 x 40.0 x 25.0

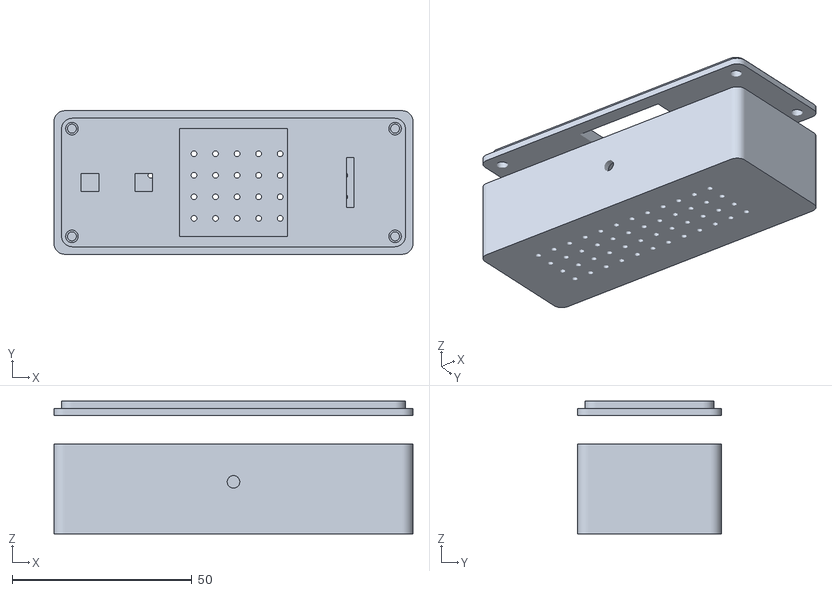
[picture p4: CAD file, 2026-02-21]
planos/ImprimibleCompletoCarcasa.stl
100.0 x 40.0 x 37.0

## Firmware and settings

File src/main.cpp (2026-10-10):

#include <Arduino.h>
#include "Config.h"
#include "Display.h"
#include "MyLora.h"
#include "Morse.h"
#include "States.h"
#include "Historial.h"
#include "Identity.h"
#include "Frasero.h"
#include "Clock.h"
#include "Chat.h"

#if defined(ESP8266)
#include <ESP8266WiFi.h>
#endif

// ============================================================
// setup
// ============================================================
void setup() {

  Serial.begin(115200);

#if defined(ESP8266)
  // El proyecto NO usa WiFi, pero el ESP8266 enciende el modem al arrancar
  // (gasta ~decenas de mA para nada). Apagarlo (modo NULL) es el mayor ahorro
  // de batería y no afecta a nada del firmware.
  WiFi.mode(WIFI_OFF);
#endif

  setupPins();

  // En hardware real las globales arrancan en su valor inicial; en el simulador
  // un "reboot" re-llama setup() sin reinicializarlas, así que las fijamos aquí
  // explícitamente para que un reinicio sea fiel: arranca en IDLE y sin temporizadores
  // colgados (si no, tras un reinicio en frío millis()-lastInteraction se desbordaría
  // y entraría en suspensión de inmediato).
  mainState        = STATE_IDLE;
  sendSubState     = SEND_WAIT;
  lastInteraction  = millis();
  lastTimeReceived = millis();   // (para LORA_DEEP_SLEEP: "tiempo sin oir nada" cuenta desde el arranque)
  cursorPos        = 0;
  buttonPressCount = 0;
  firstPressTime   = 0;

  Display_begin();

  History_load();
  Frasero_load();
  Clock_load();          // restaura el epoch persistido (hora compartida)
  Chat_load();           // restaura la outbox (mensajes sin confirmar)

  Serial.print("[ID] Equipo #"); Serial.println(Device_id());

  Lora_begin();
}

// ============================================================
// maquina de estados principal
// ============================================================
void loop() {

  backgroundTick();   // recibe mensajes (en todo momento) y refresca pantalla

  switch (mainState) {
    case STATE_IDLE:         handleIdle();        break;
    case STATE_SLEEP:        handleSleep();       break;
    case STATE_HISTORY_MENU: handleHistoryMenu(); break;
    case STATE_GAMES_MENU:   handleGamesMenu();   break;
    case STATE_SEND_MENU:    handleSendMenu();    break;
  }
}

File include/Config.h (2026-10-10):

#ifndef CONFIG_H
#define CONFIG_H

#include <Arduino.h>

// ============================================================
// Configuración general del proyecto
// ============================================================

// Nombre y versión
#define PROJECT_NAME       "Proyecto Gogoaty"
#define PROJECT_VERSION    "V2.0"

// ------------------------------------------------------------
// Pines del hardware
// ------------------------------------------------------------

// Módulo LoRa SX127x
#define PIN_LORA_NSS       15
#define PIN_LORA_RST       16
#define PIN_LORA_DIO0      5

// Botones físicos
#define PIN_MORSE_BUTTON   4
#define PIN_FINISH_BUTTON  0
#define POT_PIN            A0

// Pantalla OLED (I2C)
#define OLED_I2C_ADDRESS   0x3C
#define OLED_SDA 2
#define OLED_SCL 3

// ------------------------------------------------------------
// Tiempos generales (ms)
// ------------------------------------------------------------

// AHORRO DE ENERGÍA OPCIONAL (en suspensión). Si no se oye NADA (ni mensajes ni balizas del compañero)
// durante este tiempo, la radio se duerme del todo: ahorra ~11 mA, pero el equipo deja de oír y de avisar
// hasta que lo despiertes (con 3 pulsaciones; al despertar emite una baliza y el compañero le reenvía lo
// pendiente). 0 = no dormir nunca la radio: siempre alcanzable (lo que necesita el aviso con la pantalla
// apagada), a cambio de ~11 mA continuos. Es el valor inicial: se puede cambiar en marcha con
// Lora_setDeepSleepMs() (p.ej. desde un futuro ajuste de "ahorro de energía"). Qué política es la buena
// depende del uso (alcanzable siempre / más autonomía) y queda pendiente de decidir; por defecto, la radio
// no se duerme nunca.
#define LORA_DEEP_SLEEP    0
#define SLEEP_TIMEOUT      300000   // inactividad -> suspender (5 min)

// Despertar desde SLEEP: nº de pulsaciones y ventana de tiempo
#define WAKE_PRESS_COUNT   3
#define WAKE_WINDOW_MS     45000

// Tiempo mínimo que permanece visible una pantalla de resultado (Enviado, etc.)
#define RESULT_MIN_MS      800

// Mantener B este tiempo en el menú principal abre "Poner la hora" (ClockSetup.h)
#define CLOCK_SETUP_HOLD_MS  1500

// Con la pantalla apagada (suspensión), un mensaje nuevo la enciende este tiempo para
// avisar (A = leer, B = cerrar; sin pulsar, vuelve a apagarse sola).
#define SLEEP_ALERT_MS       8000

// Light-sleep de la CPU durante la suspensión (gran ahorro, ESP8266).
// Ponlo a 0 si en tu placa diera problemas al despertar (recuperable con RESET).
#define ENABLE_CPU_LIGHT_SLEEP  1

// ------------------------------------------------------------
// Mensajería
// ------------------------------------------------------------

// Longitud máxima del texto de un mensaje enviable. El sobre de chat añade 3 bytes; el cifrado admite hasta
// 223 bytes de texto plano (un paquete LoRa binario de 255 B, ver SimpleCrypto.cpp), pero el historial y la
// outbox guardan 99 caracteres y un mensaje largo ocupa mucho el canal (95 B de texto = 112 B en el aire =
// 190 ms a SF7), asi que el tope sigue en 92 + 3 = 95.
// Quien componga mensajes (Morse, Rueda, Frasero) debe respetar este tope para
// que el envío no falle silenciosamente al cifrar.
#define MSG_MAX_TEXT_LEN   92

// --- Entrega fiable (reintentos) ---
// Tras enviar, si no llega el ACK se reintenta hasta MSG_RETRY_MAX veces cada
// MSG_RETRY_MS. Agotados los reintentos activos, el mensaje queda en la outbox
// y se reenvia cuando se detecta de nuevo al companero (presencia). MSG_RETRY_MS
// es mayor que el timeout de "(sin confirmar)" (3 s) para no solapar de mas.
#define MSG_RETRY_MS       5000UL
#define MSG_RETRY_MAX      3

// --- Presencia (baliza "estoy aqui") ---
// Cada equipo emite una baliza periodica; si no se oye al companero en
// PRESENCE_TIMEOUT_MS se considera "fuera de alcance".
#define BEACON_INTERVAL_MS   30000UL
#define PRESENCE_TIMEOUT_MS  90000UL
// La baliza sale cada BEACON_INTERVAL_MS +-BEACON_JITTER_MS (aleatorio): dos equipos
// encendidos a la vez no deben emitir SIEMPRE juntos (la radio no oye mientras emite:
// se taparian la baliza una y otra vez y no se verian nunca).
#define BEACON_JITTER_MS     3000UL
// Companeros que se recuerdan a la vez (presencia, bateria): con mas, se sustituye el
// que lleva mas tiempo sin oirse.
#define MAX_PEERS            4
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

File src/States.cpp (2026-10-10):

#include <Arduino.h>
#include "States.h"
#include "Display.h"
#include "MyLora.h"
#include "Morse.h"
#include "TextDial.h"
#include "Frasero.h"
#include "Inputs.h"
#include "Historial.h"
#include "Chat.h"
#include "Clock.h"
#include "Battery.h"
#include "Identity.h"
#include "playChoose4Me.h"
#include "Poker.h"
#include "RefillGame.h"
#include "TetrisCoop.h"
#include "HippoRadar.h"
#include "Doodle.h"
#include "TresEnRaya.h"
#include "ClockSetup.h"

#if defined(ESP8266)
extern "C" {
  #include "user_interface.h"   // wifi_fpm_* (light sleep)
  #include "gpio.h"             // gpio_pin_wakeup_enable
}
#endif

//=============================================================
// INICIALIZACIÓN DE VARIABLES
//=============================================================

unsigned long lastInteraction = 0;
unsigned long lastTimeReceived = 0;
int cursorPos = 0;
int buttonPressCount = 0;
unsigned long firstPressTime = 0;

MainState mainState = STATE_IDLE;
SendSubState sendSubState = SEND_WAIT;

//=============================================================
// AVISO DE MENSAJE NUEVO
//=============================================================

// Con la pantalla apagada (suspension) backgroundTick() no puede dibujar: anota aqui el
// aviso y lo atiende handleSleep() (enciende la pantalla SLEEP_ALERT_MS con una vista previa).
static bool    g_alertPending = false;
static uint8_t g_alertFrom    = 0;
static String  g_alertText;

// Un mensaje (o dibujo) acaba de entrar en el historial, ya marcado como NO LEIDO:
//  - en el IDLE, el hipopotamo persigue el corazon (y la insignia de "Hist" sube);
//  - en suspension, se pide el aviso con la pantalla;
//  - en cualquier otro sitio (menus, juegos) queda la insignia al volver al IDLE.
static void onNewIncoming(uint8_t sender, const String &preview) {
    lastTimeReceived = millis();
    Serial.print("[Historial] no leidos: "); Serial.println(History_unreadCount());
    if (mainState == STATE_IDLE) {
        triggerAnimation(ANIM_CHASING_HEART);
    } else if (mainState == STATE_SLEEP) {
        g_alertPending = true;
        g_alertFrom = sender;
        g_alertText = preview;
    }
}

//=============================================================
// PAQUETES DE JUEGO (ver States.h)
//=============================================================
#define GAME_PKT_QUEUE 4
static String  g_gameQ[GAME_PKT_QUEUE];
static int     g_gameQRssi[GAME_PKT_QUEUE];                 // RSSI de cada paquete (el radar lo necesita: Lora_lastRssi() es el del ultimo leido)
static uint8_t g_gameQN = 0;

static void gameQueuePush(const String &raw, int rssi) {
    if (g_gameQN == GAME_PKT_QUEUE) {                       // llena: se pierde el mas antiguo (los juegos reenvian su estado)
        for (int i = 1; i < GAME_PKT_QUEUE; i++) { g_gameQ[i - 1] = g_gameQ[i]; g_gameQRssi[i - 1] = g_gameQRssi[i]; }
        g_gameQN--;
    }
    g_gameQ[g_gameQN] = raw;
    g_gameQRssi[g_gameQN] = rssi;
    g_gameQN++;
}

bool Game_nextPacket(String &out, int *rssi) {
    if (g_gameQN == 0) return false;
    out = g_gameQ[0];
    if (rssi) *rssi = g_gameQRssi[0];
    for (int i = 1; i < (int)g_gameQN; i++) { g_gameQ[i - 1] = g_gameQ[i]; g_gameQRssi[i - 1] = g_gameQRssi[i]; }
    g_gameQ[--g_gameQN] = "";
    return true;
}

void Game_dropPackets() {
    for (int i = 0; i < GAME_PKT_QUEUE; i++) g_gameQ[i] = "";
    g_gameQN = 0;
}

//=============================================================
// SERVICIO DE FONDO
//=============================================================

// Atiende la radio y refresca la pantalla. Es el ÚNICO punto donde se reciben
// mensajes, así que basta con llamarlo desde el bucle principal y desde
// cualquier espera bloqueante (menús, juegos...) para poder recibir en todo
// momento, esté donde esté el usuario.
void backgroundTick() {
    Lora_update();

    if (Lora_hasMessage()) {
        lastTimeReceived = millis();         // se oye al compañero: no hace falta dormir la radio
        String raw = Lora_readMessage();
        String text; uint8_t sender = 0, msgId = 0;
        ChatKind kind = Chat_parse(raw, text, sender, msgId);
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

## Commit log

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2025-12-08 Gestion de animaciones y framrate rework
    [Display.cpp, Inputs.cpp, States.cpp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]
2025-12-10 Corregido reset y limpieza de animacion ZZZ
    [Display.cpp, Inputs.cpp]
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2025-12-10 Corregir bug titulo submenu envio
    [States.cpp]
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2025-12-12 FIn de testeo y corrección bug menu historial cuando está vacío
    [States.cpp, main.cpp]
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2025-12-13 Mejorada fluidez y eliminado reseteo involuntario de animaciones
    [Display.cpp]
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2026-02-21 Correción de error de BOM y nuevo formato legible en vista previa
2026-02-21 Correción de titulo duplicado y error de formato de tabla BOM
2026-02-21 Ficheros impresión carcasa provisionales
    [ImprimibleBaseCarcasa.stl, ImprimibleTapaCarcasa.stl]
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2026-02-21 Separar ficheros de impresión de preview
    [ImprimibleBaseCarcasa.stl, ImprimibleCompletoCarcasa.stl, ImprimibleTapaCarcasa.stl]
2026-02-21 Recolocar ImprimibleBaseCarcasa.stl
    [ImprimibleBaseCarcasa.stl]
2026-02-21 Recolocar ImprimibleTapaCarcasa.stl
    [ImprimibleTapaCarcasa.stl]
2026-02-21 Eliminar plantilla defectuosa
    [ImprimibleBaseCarcasa.stl]
2026-02-21 Eliminar la otra plantilla defectuosa
    [ImprimibleTapaCarcasa.stl]
2026-02-21 Reemplazar por las plantillas correctas
    [ImprimibleBaseCarcasa.stl, ImprimibleTapaCarcasa.stl]
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2026-06-06 Corregir bugs de navegacion de menus y optimizar el codigo
    Bugs de navegacion:
    - Juegos: eliminada la pantalla 'Proximamente' fantasma al salir del Poker
    - Morse: corregido el autocancelado al entrar (primeraVezMenu defeated el timer)
    - Sleep: deteccion de flanco para que despertar exija 3 pulsaciones reales
    - Historial: reset de seleccion/scroll al entrar y primer dibujado coherente
    - Historial: reescrito a modelo lineal (borrado ya no corrompe la lista) y
    corregido overflow de 1 byte entre slots de EEPROM
    - Choose4Me: 'Otra vez' iterativo en vez de recursivo (evita desbordar la pila)
    Optimizaciones (sin perder funcionalidad):
    - Display_update respeta el intervalo de refresco (no vuelca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
    [Display.cpp, Historial.cpp, Inputs.cpp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]
2026-06-07 Anadir simulador nativo de PC que ejecuta el firmware real
    Simulador en sim/ que compila ../src tal cual (misma setup/loop, mismo
    Adafruit_GFX y tiny-AES) contra una capa mock de Arduino, para probar las
    funcionalidades y la navegacion sin hardware.
    - Capa mock Arduino: Arduino.h/String/Print, Wire, SPI, EEPROM (respaldada en
    fichero), LoRa (SX1276 con captura TX e inyeccion RX), y Adafruit_SH1107 host
    sobre el Adafruit_GFX real (render 128x128 pixel-perfect).
    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
2026-06-07 Eliminar el simulador Wokwi (sustituido por el simulador nativo de PC)
    Quita wokwi.toml, diagram.json, lib/Wokwi_Mock y el entorno [env:wokwi] de
    platformio.ini. El simulador nativo de sim/ lo reemplaza con mayor fidelidad y
    pruebas automatizables. Se conserva planos/diagramaFisicoReal.json como
    documentacion del cableado real.
2026-06-07 Simulador: render braille y controles del modo interactivo
    - Render del OLED en terminal con caracteres braille (2x4 px/caracter): la
    pantalla pasa de 64 a 32 filas y los pixeles quedan cuadrados, a tamano
    parecido al hardware real.
    - Modo interactivo: potenciometro con flechas arriba/abajo (en vez de j/k) y
    las asignaciones de teclas se muestran bajo la pantalla en todo momento.
2026-06-07 Historial: ver mensaje completo, y confirmacion de envio visible
    Fix 1: en el historial, pulsar MORSE abre el mensaje seleccionado y lo muestra
    completo (con salto de linea por palabras y la antiguedad). Desde la vista, A
    borra (con su confirmacion) y B vuelve a la lista. Antes el texto se truncaba a
    15 caracteres y no habia forma de leerlo entero.
    Fix 2: las pantallas de resultado del envio (Enviado/Error/Cancelado) se
    mantienen un tiempo minimo (800 ms) y esperan a soltar el boton antes de
    continuar, para que la confirmacion siempre se vea (antes podia aparecer un
    solo instante segun cuando se soltara el boton).
    Tests del simulador actualizados (7/7 OK) y firmware real compila sin cambio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
    [States.cpp]
2026-06-07 Recibir mensajes en todo momento (en cualquier pantalla)
    Antes los mensajes LoRa solo se recibian en la pantalla principal (IDLE) y se
    perdian estando en cualquier menu o juego.
    Solucion: una unica funcion backgroundTick() (atender radio + refrescar
    pantalla) que centraliza la recepcion y se llama desde el bucle principal y
    desde TODAS las esperas/bucles bloqueantes (menus, juegos, confirmaciones,
    pantalla de envio, vista del historial). Sin duplicar codigo: Lora_update() y
    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
2026-06-07 Fixes 4, 5, 6 y 8: IV aleatorio, bitmaps fuera de la cabecera, limpieza y ahorro en suspension
    Fix 4 (cifrado): IV aleatorio por mensaje en SimpleCrypto. Antes el IV era fijo
    (mismo texto -> mismo cifrado). Ahora se genera un IV con el RNG por hardware del
    ESP8266 (random() en el simulador) y viaja en claro al principio del paquete;
    decrypt lo lee del prefijo. Verificado: el mismo mensaje produce cifrados
    distintos y el round-trip (descifrado) sigue siendo correcto.
    Fix 5 (limpieza): los 54 bitmaps salen de Display.h a src/Bitmaps.cpp; en la
    cabecera quedan como 'extern'. Display.h pasa de 2159 a 131 lineas. El tamano de
    flash no cambia (los no usados se siguen descartando con --gc-sections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
    [Config.h, Display.cpp, States.cpp]
2026-06-07 Ahorro de bateria: apagar WiFi y light-sleep de CPU en suspension
    El firmware no usa WiFi pero el ESP8266 enciende el modem al arrancar. Se apaga
    con WiFi.mode(WIFI_OFF) -> ahorro de varias decenas de mA, totalmente seguro.
    Ademas, en el estado SLEEP la CPU entra en light-sleep (~70 mA -> ~1-2 mA) y
    despierta por GPIO al pulsar un boton. A prueba de bloqueos:
    - temporizador finito de 1 s (si fallara el GPIO-wake, la CPU vuelve sola),
    - el boton RESET siempre recupera,
    - interruptor ENABLE_CPU_LIGHT_SLEEP (Config.h) para desactivarlo si diera
    problemas en la placa (el WiFi-off seguiria activo).
    Codigo ESP8266-especifico bajo #ifdef (el simulador no se ve afectado).
    Verificado: compil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
    [Config.h, States.cpp, main.cpp]
2026-06-10 Poker: motor de manos correcto, reglas correctas y UI mejorada
    Correcciones (antes daba ganadores/empates mal):
    - Evaluador de manos reescrito con kickers, rueda A-2-3-4-5 y escalera de color
    (validado contra casos conocidos). Se acaban los empates falsos.
    - Reglas heads-up correctas: ciegas que rotan con el repartidor, opcion de la
    ciega grande preflop, turnos correctos, y all-in con devolucion del excedente
    (las fichas ya no se pierden; conservacion verificada en 8+ manos).
    Mejoras de experiencia:
    - Mas agil (menos pausas).
    - Se muestra TU jugada actual (TU JUGADA / CARTA ALTA...) en vez de las cartas
    ocultas del rival (que solo se revelan en el showdown).
    - Distintivo del reparti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
2026-06-11 Sim: modo interactivo sin bloqueos (teclado en vivo) + teclas con guion
    El modo interactivo agotaba un 'deadline' cuando el firmware se quedaba
    esperando una pulsacion (juegos/menus), soltaba el aviso de bloqueo y no se
    podia entrar a jugar.
    Ahora el motor llama a un pump-hook desde cada delay(): en modo interactivo se
    sondea el teclado EN VIVO mientras el firmware esta bloqueado, se redibuja a
    ~30 fps y se corre en tiempo real, sin deadline. Asi se puede entrar y jugar a
    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
2026-06-12 Sim: pixeles cuadrados, ritmo calibrado y arranque sin parpadeo
    - Render con medios bloques (▀▄█): pixeles cuadrados y solidos como el OLED,
    manteniendo los 128x128. Si la ventana no da (mide el terminal por DSR), cae a
    braille compacto para no cortar la parte de arriba, avisando como agrandar.
    - Ritmo fijo calibrado contra el hardware real (sim a tiempo de pared iba mas
    rapido); sin control de velocidad.
    - Arranque sin el frame inicial 'distinto': se mide el terminal ANTES del primer
    fotograma, asi sale directo en el modo correcto. Cursor oculto durante el
    render (y restaurado al salir, incluso con Ctrl+C).
    Firmware intacto. Suite del simulador 12/12.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
    [sim_main.cpp]
2026-06-12 RefillGame: juego de la cerveceria (jarra, caudal con potenciometro)
    Nuevo juego (#3 del menu, antes 'Proximamente'):
    - Van llegando jarras a la cola (arriba); cada una muestra la marca de nivel a
    la que habra que llenarla. En el grifo, MANTEN A para servir y el
    potenciometro regula el caudal (curva de valvula + suavizado: hilo fino para
    precision, chorro fuerte abriendo); suelta A para entregar.
    - Puntos por cercania a la marca + rapidez. Desbordar o quedarse corto cuesta
    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
2026-06-12 Tetris Coop: tablero compartido con 2 piezas + bot fuerte (modo solo)
    Renombrado Tetris2v2 -> Tetris Coop (menu e interno). Tetris clasico pero con
    DOS piezas a la vez en el mismo tablero, compartiendo puntuacion: hay que
    coordinarse para no chocar ni dejar agujeros.
    - Motor completo: 7 piezas con rotaciones, gravedad, bolsa de 7, limpiado de
    lineas, fin de partida.
    - Dos piezas activas que colisionan entre si; una solo se fija al apoyarse en la
    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
2026-06-12 Tetris Coop: modo 2 jugadores por LoRa (crear/unirse)
    Anade el modo cooperativo entre dos equipos por radio, ademas del bot:
    - Menu de modo: Solo (vs Bot) / 2 Jug: Crear (host) / 2 Jug: Unirse (cliente).
    - Lobby con handshake (el host anuncia, el cliente busca).
    - Host-autoritativo: el host simula la partida (su pieza + la del companero),
    difunde el estado completo del tablero (~280 ms) y aplica el input recibido a
    la segunda pieza. Gravedad mas lenta para tolerar el retardo de la radio.
    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
2026-06-12 Tetris Coop: CPU cooperativa (no VS), bot mas autonomo y tablero mayor
    - 'Solo (vs Bot)' -> 'Jugar con CPU'; HUD muestra CPU/COOP (es cooperativo, no
    un rival).
    - El bot deja sitio al jugador: penaliza colocar pegado a tu pieza, asi no te
    bloquea el movimiento.
    - El bot juega mas a su aire: si tu pieza le estorba, tiene paciencia breve y
    luego coloca la suya (ya no se queda esperando indefinidamente); ademas actua
    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
2026-06-12 Tetris Coop: CPU cooperativa de verdad, mas tranquila y sin atascos
    Arregla el comportamiento de la CPU (antes iba muy rapida y se notaba que
    construia su propia torre y luego esperaba):
    - Coopera de verdad: planifica contando con DONDE va a caer tu pieza, para
    completar filas juntos, en vez de construir por su cuenta (quitada la
    penalizacion por cercania que la segregaba a su lado).
    - Mas tranquila: coloca arriba rapido y LIMPIO (antes la gravedad la arrastraba
    y fijaba piezas en columnas equivocadas, dejando torres y huecos), pero baja
    despacio.
    - No te bloquea: si tu pieza le estorba, se desliza por debajo para esquivarte en
    vez de quedarse pegada esperando.
    - Anti-atasco: si e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
2026-06-15 Corrige 4 defectos de UX detectados en user testing (#1, #2, #3, #5)
    #1 Confirmacion de entrega con ACK tardio: un ACK que llega despues de los
    3 s (LoRa lento/colisiones) ahora repinta "Entregado!" en vez de quedarse
    en "(sin confirmar)". updateSendResultScreen() permite la transicion
    fase 2 -> fase 1; solo "Entregado!" es terminal.
    #2 Gestion de piezas del Frasero: el cursor arranca en el slot 1 aunque el
    pote venga de compose en un extremo. "Pot-lock" de entrada: el cursor no
    se mueve hasta detectar un giro real del pote.
    #3 Rueda de letras: la pista "(manten B = ...)" dice "guardar" al crear/editar
    una pieza propia y "enviar" al componer un mensaje. drawDial() recibe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
    [Display.cpp, Frasero.cpp, States.cpp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]
2026-06-16 Pote en bandas iguales + topes de longitud; corrige regresiones de test
    Firmware:
    - Inputs.getPotValue: reparto del ADC en bandas IGUALES por opcion, de modo
    que la ULTIMA opcion ocupa una banda ancha y se alcanza sin llegar a
    raw==1023 exacto (inalcanzable en ADC reales con el filtro de ruido).
    - Topes de longitud para no fallar al cifrar en silencio: MSG_MAX_TEXT_LEN=92
    (sobre de chat 3B + limite de SimpleCrypto 95) en Morse, y dialSetMaxLen()
    para que el Frasero no escriba mas de lo que cabe en una pieza (24).
    - States.backgroundTick: no ensuciar el historial con paquetes de protocolo de
    juego sin sobre (Tetris TS/TI/TH/TJ/TQ, HippoRadar HR) si los oye un tercero.
    - HippoRadar: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
    [Config.h, Frasero.cpp, Inputs.cpp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]
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2026-10-05 Fix: frame 2 del hipopotamo leia 8 bytes fuera de hippoBitMap62
    animateHippo() y animateHippoWithZzz() dibujaban hippoBitMap62 (62x62, 496
    bytes) como 63x63 (504 bytes), leyendo memoria ajena al final del bitmap.
    Detectado con AddressSanitizer en el simulador. Ahora 62x62, igual que el
    frame 6.
    [Display.cpp]
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2026-10-05 Simulador: los errores de guion y de uso ya no pasan en silencio
    - Comando o comprobacion desconocidos ("expect txt", "expct"), argumentos que
    faltan o no validos (expect pixel ... encendido, tap mrose, wait sin ms...)
    cuentan como [FAIL] con el numero de linea: antes el test pasaba sin
    comprobar nada.
    - chatmsg / lora rx con mas de 95 bytes (lo que cifra el firmware) decian
    "inyectado" pero inyectaban un paquete vacio: ahora es un error del guion.
    - Una captura que no se puede guardar cuenta como FAIL; las carpetas de
    --shots y --eeprom se crean si no existen (antes no habia persistencia).
    - Si la EEPROM no se puede escribir se avisa por stderr.
    - Opcion desconocida o sin valor y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
    [sim_main.cpp, sim_runtime.cpp]
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2026-10-10 Varios equipos: tabla de companeros, bateria minima y balizas con jitter
    - Chat recuerda hasta MAX_PEERS (4) companeros por separado (id, ultimo oido, bateria,
    aviso de bateria baja); tabla llena: se olvida el que lleva mas tiempo sin oirse. La
    presencia es 'algun companero en alcance'; la bateria en pantalla es el nivel MAS BAJO de
    los que estan en alcance (y '!' si alguno avisa), ya no el del ultimo que emitio. Un equipo
    que aparece reactiva los reintentos de lo pendiente.
    - Dedup de recepcion de 8 a 16 mensajes (con varios equipos entran mas mensajes y reintentos).
    - Balizas con jitter (30 s +-3 s; la 1a a los 2-4 s): dos equipos encendidos a la vez no
    emitian SIEMPRE juntos (la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
    [Chat.cpp, Config.h, sim_main.cpp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]
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2026-10-10 Manual de usuario en el README y documentacion sincronizada
    - README.md: manual de usuario completo (conexiones por pin, compilacion con PlatformIO, controles,
    pantalla principal, los cinco modos de envio, confirmacion de entrega, historial, avisos y
    suspension, puesta de hora, juegos, radio y solucion de problemas) a partir de lo que hace el
    firmware y de sus pantallas.
    - path.md: fecha y commit, fila de manual, riesgo del identificador de 1 byte (dos equipos pueden
    coincidir), recuento de tests y escenas.
    - sim/README.md y sim/linux/README.md: consejos para escribir tests robustos con la radio realista,
    SIM_SEED, demos/, net_test con tiempo sincronizado.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
2026-10-11 Partidas entre dos firmwares reales: arreglos de protocolo, acceso al canal sin bloquear y mas pruebas
    Se enfrentan por primera vez dos firmwares REALES jugando entre si (3 en raya, Tetris Coop, HippoRadar) en el simulador
    con tiempo sincronizado y varias semillas aleatorias. Salieron estos defectos, ya corregidos y con su prueba (cada
    arreglo se ha comprobado por mutacion: sin el, la prueba falla):
    - 3 en raya: el HELLO tenia periodo fijo (dos equipos en fase chocaban para siempre: 64 s sin emparejar) -> jitter.
    El emparejamiento era unilateral (quien oia primero callaba y el otro seguia "Buscando rival" hasta que jugara) ->
    quien ya esta emparejado contesta al HELLO con su es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
2026-10-11 Tetris 2J: salida cuando el otro desaparece; ACK_DELAY_MIN_MS a 80 ms
    - Cliente: si en plena partida deja de llegar el estado del anfitrion durante 6 s (HOST_LOST_MS), muestra
    "Anfitrion perdido" y sale al menu (antes se quedaba con el ultimo tablero congelado).
    - Anfitrion: al recibir el TQ del cliente muestra "El companero salio" y vuelve al lobby (antes lo ignoraba).
    - ACK_DELAY_MIN_MS 10 -> 80: el emisor, que acaba de emitir, tarda en volver a escuchar (la radio se re-arma al
    consultarla el bucle) y un ACK inmediato podia perderse.
    - Suite nueva tetris_leave; tetris_rx emula un anfitrion que sigue emitiendo; cota de dispersion de los ACK ajustada.
    - 45 suites correctas, 10 escenas mu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
2026-10-11 HippoRadar: ventanas de chat (1,2 s cada 4 s en SF7) para no quedar incomunicado
    Decision del usuario (opcion b). En la ventana la radio vuelve a SF7: se reciben y confirman mensajes y salen balizas y
    reintentos; no se emiten pings. El enlace del radar se da por perdido tras 6 s sin ping. hippo_rx reescrito; 45 suites
    y 10 escenas multi-equipo correctas, duo del radar 300/300 semillas.
    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
